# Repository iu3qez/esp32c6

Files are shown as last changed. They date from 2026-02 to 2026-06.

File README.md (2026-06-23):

# C6MacroSwitch

Interruttore/scene-controller Zigbee a batteria basato su ESP32-C6-WROOM-1-N8:
6 tasti meccanici Kailh Choc, LED di stato, alimentazione Li-ion 1S con LDO
very-low-dropout (XC6220B331), USB-C per programmazione via USB nativo,
charger MCP73831 predisposto ma non montato (DNP).

Progetto [Zener](https://github.com/diodeinc/pcb) (`pcb` CLI, richiede KiCad 10.x).

- Spec: `../docs/superpowers/specs/2026-06-11-c6-zigbee-macro-switch-design.md`
- Sourcing LCSC: `SOURCING.md`

## Comandi

```bash
pcb build C6MacroSwitch.zen    # valida il design
pcb layout C6MacroSwitch.zen   # sincronizza layout/C6MacroSwitch/layout.kicad_pcb
pcb open C6MacroSwitch.zen     # apre il layout in KiCad
pcb bom C6MacroSwitch.zen      # BOM con sourcing
```

Il round-trip KiCad 10 (salvataggio nativo → `pcb build`/`pcb layout`) è
verificato e funziona.

## Mappa GPIO

| GPIO | Funzione |
|---|---|
| IO0–IO5 | Tasti macro KEY1–KEY6 (LP-GPIO: wake da deep sleep, pull-up interni) |
| IO6 | ADC partitore batteria (1M/1M + 100nF) |
| IO8 | strapping, pullup 10k (download mode) |
| IO9 | Boot (pull-up 10k + tasto) |
| IO10 | LED di stato (verde, attivo alto) |
| IO12/IO13 | USB D−/D+ (USB nativo) |
| EN | Reset (pull-up 10k + 1µF + tasto) |

## Alimentazione

```
J_BAT (JST-PH) → Q_RVP/D_RVP (protezione inversione) → J_IMEAS (jumper misura corrente) → XC6220 → 3V3
USB VBUS → MCP73831 (DNP) → BAT+   |   USB VBUS → 1N5817W (DNP) → ingresso LDO
```

- Rimuovendo lo shunt da J_IMEAS si misura l'assorbimento totale a batteria.
- Protezione inversione batteria: montare ESATTAMENTE UNO tra Q_RVP
  (AO3401A, basse perdite) e D_RVP (1N5817W, semplice, ~300 mV di caduta);
  mai entrambi.
- D_USB_PWR (DNP) permette flash/test da USB senza batteria.
  **Attenzione:** mai montarlo con batteria collegata e jumper J_IMEAS
  inserito (bypassa il charger).
- Charger e relativi R/LED tutti DNP sulle prime board.
- Cutoff batteria firmware consigliato ~3,4 V (sotto, il rail esce di
  regolazione durante i burst TX).

## Note di popolamento

- SW1–SW6 (Kailh Choc CPG135001D01): esauriti su LCSC, montaggio in proprio.
- Tutti i passivi 0603

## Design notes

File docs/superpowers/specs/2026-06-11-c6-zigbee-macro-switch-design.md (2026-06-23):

# Design: C6 Zigbee Macro Switch (variante Zener)

Data: 2026-06-11
Branch: `dev-zener`
Stato: in attesa di approvazione spec

## Contesto e motivazione

Il progetto atopile originale (dev board ESP32-C6 con CH340G, doppio USB-C,
header verso keypad esterno) è bloccato: atopile ≤0.15.7 non rilegge i
`.kicad_pcb` salvati da KiCad 10 (issue atopile#1822). Si riparte prendendo
solo l'idea di fondo e si migra a `pcb` di Diode Inc. (linguaggio Zener,
file `.zen`), che richiede nativamente KiCad 10.x.

Il vecchio progetto ato resta nel repo come riferimento, intatto.

## Cosa si costruisce

Un interruttore/scene-controller **Zigbee a batteria** basato su ESP32-C6:
6 tasti macro, 1 LED di stato, alimentazione Li-ion 1S con LDO
very-low-dropout / low-IQ, USB-C per programmazione, charger predisposto ma
non montato (DNP) sulle prime board.

## Vincoli vincolanti (richieste esplicite)

1. **Modulo**: ESP32-C6-WROOM-1-N8, identico al progetto precedente
   (LCSC **C5366877**) — già disponibile in casa.
2. **Connettore USB-C**: identico al progetto precedente, Korean Hroparts
   TYPE-C-31-M-12 (LCSC **C165948**).
3. **Tasti macro**: switch meccanici Kailh Choc CPG135001D01
   (LCSC **C400229**), identici al keypad del progetto precedente.
4. **Tutti gli altri componenti**: disponibili su **LCSC con stock > 0** al
   momento del part picking.
5. **Resistenze e condensatori: package 0603**.
6. Toolchain: `diodeinc/pcb` (Zener), nuovo branch `dev-zener`.

## Architettura

```
USB-C (C165948) ──VBUS──> [Charger MCP73831/TP4054, DNP] ──> BAT+
   │ D+/D-                                                    │
   │                                              JST-PH 2p ──┤
   └──> ESP32-C6 USB nativo (GPIO12/13)                       │
                                                              ▼
                                            J_IMEAS (jumper misura corrente)
                                                              │
                                                              ▼
                                       LDO 3.3V VLDO/low-IQ (XC6220B331*)
                                                              │
                                                              ▼
ESP32-C6-WROOM-1-N8 (C5366877) <── 3V3 ── partitore ADC batteria (≥1 MΩ)
   ├── GPIO0..GPIO5: 6 tasti macro (2×3), LP-GPIO, wake da deep sleep,
   │                 pull-up interni → nessuna resistenza esterna
   ├── GPIO8 (o libero): LED di stato (normalmente spento)
   ├── EN: pull-up 10k + C 1uF + tasto reset
   └── GPIO9: tasto boot (pull-up interno/10k)
```

\* Candidato primario LDO: Torex XC6220B331 (1 A, dropout ~100 mV @ 300 mA,
IQ ~8 µA). Fallback se non a stock su LCSC: TLV755P-33, ME6217C33.
La scelta finale si fa in fase di picking col vincolo stock > 0.

## Componenti

| Blocco | Parte | Note |
|---|---|---|
| MCU/radio | ESP32-C6-WROOM-1-N8 | LCSC C5366877, fissato |
| USB-C | TYPE-C-31-M-12 | LCSC C165948, fissato; CC1/CC2 pulldown 5.1k 0603 |
| LDO | XC6220B331 (candidato) | SOT-25; cap in/out ceramici 0603 (valori da datasheet, tipicamente 1–10 µF) |
| Charger (DNP) | MCP73831 o TP4054, SOT-23-5 | + R prog 0603 + LED charge; footprint montati, BOM vuota |
| Batteria | JST-PH 2 pin SMT | Li-ion/LiPo 1S |
| Misura corrente | header 2 pin 2.54 mm + shunt | in serie al positivo batteria (a monte dell'LDO): shunt rimosso → amperometro in serie; misura il consumo totale incluso IQ dell'LDO |
| Alimentazione da USB senza batteria | Schottky SOD-123 (DNP) | da VBUS all'ingresso LDO (a valle del jumper): permette flash/test senza batteria; DNP se non serve. L'LDO regge Vin 5 V |
| Monitor batteria | 2× R ≥1 MΩ 0603 + C filtro | su ADC del C6 |
| Tasti macro | 6× Kailh Choc CPG135001D01 | LCSC **C400229**, switch meccanico low-profile come nel keypad precedente (footprint/symbol già in `parts/Kailh_CPG135001D01/`) |
| Tasti servizio | 2× tattile SMD (reset + boot) | LCSC stock >0 |
| LED stato | LED 0603 + R 1k 0603 | su GPIO libero |
| EN | R 10k + C 1 µF 0603 | reset RC classico |

Decoupling: 100 nF 0603 vicino al modulo + bulk 10 µF 0603 sul rail 3V3
(il WROOM ha già i regolatori interni di decoupling principali on-module;
si segue la app note Espressif).

## Connessioni GPIO

| GPIO | Funzione | Perché |
|---|---|---|
| GPIO0–GPIO5 | 6 tasti macro verso GND | LP-GPIO: deep-sleep wake, pull-up interni |
| GPIO9 | Boot + tasto | strapping pin standard |
| GPIO12/13 | USB D-/D+ | USB nativo (flash + console) |
| EN | Reset + RC | |
| GPIO8 | LED stato | strapping ma utilizzabile come output LED |
| GPIO6 | ADC partitore batteria | ADC1_CH6, ultimo canale ADC libero (canali ADC del C6: GPIO0–6) |

Nota: se in fase di implementazione emerge un conflitto su GPIO6, si sposta
un tasto su un GPIO non-LP accettando il wake solo dagli altri 5 tasti.

## Struttura progetto Zener

```
zener/                      # nuovo workspace pcb, non tocca il progetto ato
  pcb.toml                  # manifest board + dipendenze registry
  C6MacroSwitch.zen         # board top-level
  components/               # parti locali (WROOM-1-N8, TYPE-C-31-M-12, ...)
    ...                     # .zen + .kicad_sym + .kicad_mod riusati dal vecchio repo dove possibile
  layout/                   # output pcb layout (.kicad_pcb)
```

- Generici (R, C, LED, JST, tactile) da `@stdlib` o dal registry diodeinc
  (`pcb search`), con vincolo LCSC stock > 0.
- Per WROOM-1-N8 e TYPE-C-31-M-12 si riusano simbolo/footprint KiCad già
  presenti in `parts/` del progetto ato (sono già verificati su board
  precedente), incapsulati in componenti Zener locali.
- Skill di lavoro installate in `.claude/skills/` (zener-language,
  registry-search, librarian, datasheet-reader, spice-sim): da usare in
  implementazione.

## Verifica / criteri di successo

1. `pcb build` senza errori sul board top-level.
2. `pcb layout` genera un `.kicad_pcb` che KiCad 10.0.3 apre senza warning
   di formato; round-trip salvataggio KiCad 10 → `pcb build` OK.
3. BOM: ogni parte (tranne modulo già in casa) con codice LCSC e stock > 0
   alla data del picking; R/C tutti 0603.
4. Netlist coerente con la tabella GPIO sopra (review manuale).

## Fuori scope

- Layout/sbroglio finale e forma della scheda (fase successiva).
- Firmware Zigbee.
- Ricarica montata (prime board: charger DNP).

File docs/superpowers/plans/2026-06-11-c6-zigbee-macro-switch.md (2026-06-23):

# C6 Zigbee Macro Switch — Implementation Plan (Zener/pcb)

> **For agentic workers:** REQUIRED SUB-SKILL: Use superpowers:subagent-driven-development (recommended) or superpowers:executing-plans to implement this plan task-by-task. Steps use checkbox (`- [ ]`) syntax for tracking.

**Goal:** Board Zener completa e validata (`pcb build` pulito, layout generato apribile in KiCad 10) per l'interruttore Zigbee a batteria con ESP32-C6, secondo la spec `docs/superpowers/specs/2026-06-11-c6-zigbee-macro-switch-design.md`.

**Architecture:** Workspace `pcb` (board repository) in `zener/` sul branch `dev-zener`. Componenti specifici come moduli Zener locali in `zener/components/`, riusando i `.kicad_sym`/`.kicad_mod` già verificati in `parts/` del progetto ato. Generici (R, C, LED, header) da `@stdlib`. Top-level `C6MacroSwitch.zen` con catena di potenza batteria→jumper→LDO→3V3, 6 tasti Choc su GPIO0–5, LED su GPIO8, USB nativo su IO12/13.

**Tech Stack:** `pcb` CLI (diodeinc), linguaggio Zener (Starlark), KiCad 10.0.3, stdlib `@stdlib`.

**Regole trasversali (valgono per OGNI task):**
- Prima di scrivere/modificare `.zen`: skill `zener-language` già caricata in `.claude/skills/`.
- Dopo ogni modifica agli import: `pcb sync` dentro `zener/`, poi `pcb build`.
- R/C sempre `package="0603"`.
- Ogni parte nuova: verificare LCSC stock > 0 (vedi Task 8) prima di fissarla.
- Preservare eventuali commenti `# pcb:sch`.
- Commit frequenti, messaggi conventional-commits, MAI Co-Authored-By.

---

### Task 1: Installare il tool `pcb`

**Files:** nessuno (toolchain).

- [ ] **Step 1: Installa**

```bash
curl -fsSL https://raw.githubusercontent.com/diodeinc/pcb/main/install.sh | bash
```

Installa in `$HOME/.local/bin` (già nel PATH: `ato` sta lì).

- [ ] **Step 2: Verifica**

```bash
pcb --version
```

Atteso: versione ≥ 0.3.92. Se il comando non esiste, `export PATH="$HOME/.local/bin:$PATH"`.

- [ ] **Step 3: Verifica che trovi KiCad**

```bash
kicad-cli version   # atteso: 10.0.3
```

Nessun commit (nessun file di repo toccato).

---

### Task 2: Scaffold del workspace `zener/`

**Files:**
- Create: `zener/pcb.toml`
- Create: `zener/C6MacroSwitch.zen`

- [ ] **Step 1: Genera lo scaffold con il tool** (così la struttura è quella canonica della versione installata)

```bash
cd /home/sf/src/esp32c6/esp32c6
pcb new board C6MacroSwitch https://github.com/iu3qez/esp32c6
```

Se `pcb new board` crea una directory `C6MacroSwitch/`, rinominarla in `zener/`:

```bash
mv C6MacroSwitch zener
```

Ispeziona cosa ha generato (`ls -R zener/`) e adatta i passi seguenti alla struttura reale; i contenuti sotto sono il riferimento atteso.

- [ ] **Step 2: `zener/pcb.toml`** (verifica/adatta quello generato)

```toml
[workspace]
name = "esp32c6-zener"

[board]
name = "C6MacroSwitch"
path = "C6MacroSwitch.zen"
description = "ESP32-C6 Zigbee battery-powered macro switch"
```

- [ ] **Step 3: Board minimale `zener/C6MacroSwitch.zen`**

```zen
Board(name="C6MacroSwitch", layout_path="layout/C6MacroSwitch", layers=2)

VBAT = Power("VBAT")
VDD_3V3 = Power("3V3")
GND = Ground("GND")
```

- [ ] **Step 4: Valida**

```bash
cd zener && pcb build
```

Atteso: build OK, zero errori (board vuota è legale; se `Board()` richiede argomenti diversi nella versione installata, vedere `pcb doc --package @stdlib` per `board_config`).

- [ ] **Step 5: Commit**

```bash
git add zener && git commit -m "feat(zener): scaffold pcb workspace for C6MacroSwitch"
```

---

### Task 3: Componente ESP32-C6-WROOM-1-N8 (riuso footprint/symbol)

**Files:**
- Create: `zener/components/ESP32C6WROOM1N8/ESP32C6WROOM1N8.zen`
- Copy: `parts/Espressif_Systems_ESP32_C6_WROOM_1_N8/ESP32-C6-WROOM-1-N8.kicad_sym` → `zener/components/ESP32C6WROOM1N8/`
- Copy: `parts/Espressif_Systems_ESP32_C6_WROOM_1_N8/WIRELM-SMD_ESP32-C6-WROOM-1.kicad_mod` → `zener/components/ESP32C6WROOM1N8/`

- [ ] **Step 1: Copia symbol e footprint**

```bash
mkdir -p zener/components/ESP32C6WROOM1N8
cp parts/Espressif_Systems_ESP32_C6_WROOM_1_N8/ESP32-C6-WROOM-1-N8.kicad_sym zener/components/ESP32C6WROOM1N8/
cp parts/Espressif_Systems_ESP32_C6_WROOM_1_N8/WIRELM-SMD_ESP32-C6-WROOM-1.kicad_mod zener/components/ESP32C6WROOM1N8/
```

- [ ] **Step 2: Ispeziona i nomi pin del symbol** (servono per la mappa `pins`)

```bash
grep -oE '\(name "[^"]+"' zener/components/ESP32C6WROOM1N8/ESP32-C6-WROOM-1-N8.kicad_sym | sort -u
grep -oE '\(number "[^"]+"' zener/components/ESP32C6WROOM1N8/ESP32-C6-WROOM-1-N8.kicad_sym | sort -u
```

Pinout di riferimento (dal part ato, verificato su board precedente): EN=3, GND=1,28–37, IO0=8, IO1=9, IO2=27, IO3=26, IO4=4, IO5=5, IO6=6, IO7=7, IO8=10, IO9=15, IO10=11, IO11=12, IO12=13, IO13=14, IO15=23, IO18=16, IO19=17, IO20=18, IO21=19, IO22=20, IO23=21, P3V3=2, RXD0=24, TXD0=25.

- [ ] **Step 3: Scrivi `ESP32C6WROOM1N8.zen`**

```zen
EN = io(Net)
P3V3 = io(Power)
GND = io(Ground)
IO0 = io(Net); IO1 = io(Net); IO2 = io(Net); IO3 = io(Net)
IO4 = io(Net); IO5 = io(Net); IO6 = io(Net); IO7 = io(Net, optional=True)
IO8 = io(Net); IO9 = io(Net)
IO10 = io(Net, optional=True); IO11 = io(Net, optional=True)
IO12 = io(Net); IO13 = io(Net)
IO15 = io(Net, optional=True); IO18 = io(Net, optional=True)
IO19 = io(Net, optional=True); IO20 = io(Net, optional=True)
IO21 = io(Net, optional=True); IO22 = io(Net, optional=True)
IO23 = io(Net, optional=True)
RXD0 = io(Net, optional=True); TXD0 = io(Net, optional=True)

Component(
    name = "ESP32C6WROOM1N8",
    symbol = Symbol(library = "./ESP32-C6-WROOM-1-N8.kicad_sym"),
    footprint = "./WIRELM-SMD_ESP32-C6-WROOM-1.kicad_mod",
    part = Part(mpn = "ESP32-C6-WROOM-1-N8", manufacturer = "Espressif Systems"),
    pins = {
        "EN": EN, "P3V3": P3V3, "GND": GND,
        "IO0": IO0, "IO1": IO1, "IO2": IO2, "IO3": IO3,
        "IO4": IO4, "IO5": IO5, "IO6": IO6, "IO7": IO7,
        "IO8": IO8, "IO9": IO9, "IO10": IO10, "IO11": IO11,
        "IO12": IO12, "IO13": IO13, "IO15": IO15, "IO18": IO18,
        "IO19": IO19, "IO20": IO20, "IO21": IO21, "IO22": IO22,
        "IO23": IO23, "RXD0": RXD0, "TXD0": TXD0,
    },
)
```

Note d'adattamento (decidere in base all'output di Step 2 e di `pcb build`):
- Se il symbol espone i pin per NUMERO e non per nome, le chiavi di `pins` diventano i numeri (`"3": EN, "2": P3V3, ...` secondo il pinout di riferimento sopra).
- Se il symbol contiene già la property footprint corretta, rimuovere `footprint=` dal `Component()` (il symbol è source of truth).
- Aggiungere la property LCSC: se `pcb build`/BOM non la riporta, aggiungere `properties = {"LCSC": "C5366877"}` al `Component()`.

- [ ] **Step 4: Valida il componente**

```bash
cd zener && pcb build components/ESP32C6WROOM1N8/ESP32C6WROOM1N8.zen
```

Atteso: build OK. Errori tipici: pin del symbol non mappato (aggiungerlo a `pins` con `io(Net, optional=True)`), nome pin sbagliato (correggere chiave).

- [ ] **Step 5: Commit**

```bash
git add zener/components/ESP32C6WROOM1N8
git commit -m "feat(zener): ESP32-C6-WROOM-1-N8 component (reused verified sym/fp)"
```

---

### Task 4: Componente USB-C TYPE-C-31-M-12

**Files:**
- Create: `zener/components/TYPEC31M12/TYPEC31M12.zen`
- Copy: `parts/Korean_Hroparts_Elec_TYPE_C_31_M_12/TYPE-C-31-M-12.kicad_sym` e `USB-C_SMD-TYPE-C-31-M-12_1.kicad_mod` → `zener/components/TYPEC31M12/`

- [ ] **Step 1: Copia file**

```bash
mkdir -p zener/components/TYPEC31M12
cp parts/Korean_Hroparts_Elec_TYPE_C_31_M_12/TYPE-C-31-M-12.kicad_sym zener/components/TYPEC31M12/
cp parts/Korean_Hroparts_Elec_TYPE_C_31_M_12/USB-C_SMD-TYPE-C-31-M-12_1.kicad_mod zener/components/TYPEC31M12/
```

- [ ] **Step 2: Ispeziona pin del symbol** (stesso metodo grep del Task 3, Step 2).

Pinout di riferimento ato: CC1=A5, CC2=B5, D_N=A7+B7, D_P=A6+B6, EH=1..4, GND=A1B12+B1A12, SBU1=A8, SBU2=B8, VBUS=A4B9+B4A9.

- [ ] **Step 3: Scrivi `TYPEC31M12.zen`**

```zen
load("@stdlib/interfaces.zen", "Usb2")

VBUS = io(Power)
GND = io(Ground)
USB = io(Usb2)
CC1 = io(Net)
CC2 = io(Net)
SBU1 = io(Net, optional=True)
SBU2 = io(Net, optional=True)
SHIELD = io(Net)

Component(
    name = "TYPEC31M12",
    symbol = Symbol(library = "./TYPE-C-31-M-12.kicad_sym"),
    footprint = "./USB-C_SMD-TYPE-C-31-M-12_1.kicad_mod",
    part = Part(mpn = "TYPE-C-31-M-12", manufacturer = "Korean Hroparts Elec"),
    pins = {
        "VBUS": VBUS, "GND": GND,
        "D_P": USB.DP, "D_N": USB.DM,
        "CC1": CC1, "CC2": CC2,
        "SBU1": SBU1, "SBU2": SBU2,
        "EH": SHIELD,
    },
)
```

Note d'adattamento: come Task 3 (chiavi `pins` = nomi reali del symbol; se i pad multipli A4B9/B4A9 sono pin distinti nel symbol, mappare entrambi sulla stessa net: `"A4B9": VBUS, "B4A9": VBUS`). Verificare i nomi dei campi di `Usb2` con `pcb doc --package @stdlib` (`DP`/`DM` vs `D_P`/`D_N`) e usare quelli reali.

- [ ] **Step 4: Valida**

```bash
cd zener && pcb build components/TYPEC31M12/TYPEC31M12.zen
```

- [ ] **Step 5: Commit**

```bash
git add zener/components/TYPEC31M12
git commit -m "feat(zener): TYPE-C-31-M-12 USB-C connector component"
```

---

### Task 5: Componente Kailh Choc CPG135001D01

**Files:**
- Create: `zener/components/KailhChoc/KailhChoc.zen`
- Copy: `parts/Kailh_CPG135001D01/CPG135001D01.kicad_sym` e `KEY-TH_CPG135001D0X.kicad_mod` → `zener/components/KailhChoc/`

- [ ] **Step 1: Copia file**

```bash
mkdir -p zener/components/KailhChoc
cp parts/Kailh_CPG135001D01/CPG135001D01.kicad_sym zener/components/KailhChoc/
cp parts/Kailh_CPG135001D01/KEY-TH_CPG135001D0X.kicad_mod zener/components/KailhChoc/
```

- [ ] **Step 2: Scrivi `KailhChoc.zen`** (2 pin: 1 e 2)

```zen
P1 = io(Net)
P2 = io(Net)

Component(
    name = "KailhChoc",
    symbol = Symbol(library = "./CPG135001D01.kicad_sym"),
    footprint = "./KEY-TH_CPG135001D0X.kicad_mod",
    part = Part(mpn = "CPG135001D01", manufacturer = "Kailh"),
    pins = {"1": P1, "2": P2},
)
```

(Adattare chiavi `pins` ai nomi reali del symbol come nei task precedenti.)

- [ ] **Step 3: Valida e committa**

```bash
cd zener && pcb build components/KailhChoc/KailhChoc.zen
git add zener/components/KailhChoc
git commit -m "feat(zener): Kailh Choc CPG135001D01 switch component"
```

---

### Task 6: Componenti riusati minori — tactile button e Schottky

**Files:**
- Create: `zener/components/TactileTSA061B/TactileTSA061B.zen` (+ sym/fp copiati da `parts/BZCN_TSA061B2808B/`)
- Create: `zener/components/SS1N5817W/SS1N5817W.zen` (+ sym/fp copiati da `parts/Slkor_1N5817W/`)

- [ ] **Step 1: Tactile (reset/boot), pinout ato: 1,2 = lato A; 3,4 = lato B; 5 = ground/frame**

```bash
mkdir -p zener/components/TactileTSA061B
cp parts/BZCN_TSA061B2808B/*.kicad_sym parts/BZCN_TSA061B2808B/*.kicad_mod zener/components/TactileTSA061B/
```

`TactileTSA061B.zen` (verificare i nomi file copiati e i pin reali col grep):

```zen
A = io(Net)
B = io(Net)

Component(
    name = "TactileTSA061B",
    symbol = Symbol(library = "./TSA061B2808B.kicad_sym"),
    footprint = "./KEY-SMD_4P-L6.0-W6.0-LS8.0.kicad_mod",
    part = Part(mpn = "TSA061B2808B", manufacturer = "BZCN"),
    pins = {"1": A, "2": A, "3": B, "4": B, "5": B},
)
```

- [ ] **Step 2: Schottky 1N5817W (per VBUS→LDO, DNP), pinout ato: 2=anodo, 1=catodo**

```bash
mkdir -p zener/components/SS1N5817W
cp parts/Slkor_1N5817W/*.kicad_sym parts/Slkor_1N5817W/*.kicad_mod zener/components/SS1N5817W/
```

```zen
A = io(Net)
K = io(Net)

Component(
    name = "SS1N5817W",
    symbol = Symbol(library = "./1N5817W.kicad_sym"),
    footprint = "./SOD-123_L2.8-W1.8-LS3.7-RD.kicad_mod",
    part = Part(mpn = "1N5817W", manufacturer = "Slkor"),
    pins = {"1": K, "2": A},
)
```

(I nomi esatti di sym/fp si leggono con `ls parts/BZCN_TSA061B2808B/ parts/Slkor_1N5817W/` e dai trait `is_atomic_part` nei rispettivi `.ato`; adattare.)

- [ ] **Step 3: Valida entrambi e committa**

```bash
cd zener && pcb build components/TactileTSA061B/TactileTSA061B.zen components/SS1N5817W/SS1N5817W.zen
git add zener/components/TactileTSA061B zener/components/SS1N5817W
git commit -m "feat(zener): tactile button and 1N5817W Schottky components"
```

---

### Task 7: Parti nuove — LDO, charger (DNP), JST-PH

Per ognuna: **prima** cercare nel registry (skill `registry-search`: `pcb search -m registry:components <query>`, poi `pcb search -m registry:modules <query>`); usare il package registry se esiste. Solo se assente, creare componente locale (skill `librarian` per il flusso symbol/footprint: scaricare da LCSC/EasyEDA con lo stesso metodo usato per le parti ato, o disegnare da datasheet con `datasheet-reader`).

- [ ] **Step 1: LDO XC6220B331MR-G**

```bash
cd zener && pcb search -m registry:components XC6220
pcb search XC6220B331MR-G
```

Verifica LCSC stock >0 per XC6220B331MR-G (pagina LCSC; vedi Task 8 Step 1 per il metodo). Se stock = 0, fallback nell'ordine: TLV755P-33 (`TLV75533PDBVR`), ME6217C33M5G — stesso giro di ricerca registry + stock. Il componente espone almeno: `VIN = io(Power)`, `VOUT = io(Power)`, `GND = io(Ground)` (+ `CE`/`EN` se presente nel package scelto: legarlo a VIN nel top-level).

- [ ] **Step 2: Charger MCP73831 (o TP4054)**

```bash
pcb search -m registry:components MCP73831
pcb search MCP73831
```

Stock check su `MCP73831T-2ACI/OT`; fallback `TP4054`. Servono: `VDD`, `VBAT`, `STAT`, `PROG`, `VSS`. La R di PROG (0603) fissa la corrente di carica: scegliere `2kohm` (≈500 mA) — verrà montata solo col charger, quindi `dnp=True` insieme a esso.

- [ ] **Step 3: Connettore batteria JST-PH 2 pin**

```bash
pcb search -m registry:components "JST PH"
pcb search S2B-PH-K-S
```

Candidato THT side-entry `S2B-PH-K-S` (JST) o equivalente SMT; vincolo: LCSC stock >0. Se assente nel registry, creare `zener/components/JstPh2/` col flusso librarian.

- [ ] **Step 4: Valida e committa** (file effettivi dipendono da registry vs locale)

```bash
cd zener && pcb sync && pcb build
git add zener && git commit -m "feat(zener): add LDO, charger (DNP) and battery connector parts"
```

---

### Task 8: Verifica sourcing LCSC (stock > 0)

**Files:**
- Create: `zener/SOURCING.md`

- [ ] **Step 1: Per OGNI MPN scelto nei Task 3–7, verifica stock su LCSC**

Metodo: `WebFetch` su `https://www.lcsc.com/search?q=<MPN>` oppure API pubblica `https://wmsc.lcsc.com/ftps/wm/search/global-search?keyword=<MPN>` e leggere il campo stock. In alternativa la pagina prodotto diretta se il codice C è noto (es. `https://www.lcsc.com/product-detail/C400229.html`).

- [ ] **Step 2: Compila `zener/SOURCING.md`**

```markdown
# Sourcing (LCSC) — verificato YYYY-MM-DD

| Ref | Parte | LCSC | Stock | Note |
|---|---|---|---|---|
| U1 | ESP32-C6-WROOM-1-N8 | C5366877 | n/a | già in casa |
| J1 | TYPE-C-31-M-12 | C165948 | <stock> | |
| SW1–6 | CPG135001D01 | C400229 | <stock> | |
| U2 | <LDO scelto> | <C...> | <stock> | |
| U3 | <charger> | <C...> | <stock> | DNP |
| ... | | | | |
```

Regola: se una parte ha stock 0, tornare al task corrispondente e usare il fallback. R/C 0603 generici: verificare che il valore esista su LCSC in 0603 (sono basic part, di norma sì) e annotare un codice C di riferimento.

- [ ] **Step 3: Commit**

```bash
git add zener/SOURCING.md && git commit -m "docs(zener): LCSC sourcing table with stock verification"
```

---

### Task 9: Top-level `C6MacroSwitch.zen` — wiring completo

**Files:**
- Modify: `zener/C6MacroSwitch.zen`

- [ ] **Step 1: Scrivi il top-level completo**

```zen
load("@stdlib/interfaces.zen", "Usb2")

Resistor  = Module("@stdlib/generics/Resistor.zen")
Capacitor = Module("@stdlib/generics/Capacitor.zen")
Led       = Module("@stdlib/generics/Led.zen")
PinHeader = Module("@stdlib/generics/PinHeader.zen")

Esp32   = Module("./components/ESP32C6WROOM1N8/ESP32C6WROOM1N8.zen")
UsbC    = Module("./components/TYPEC31M12/TYPEC31M12.zen")
Choc    = Module("./components/KailhChoc/KailhChoc.zen")
Tactile = Module("./components/TactileTSA061B/TactileTSA061B.zen")
Schottky = Module("./components/SS1N5817W/SS1N5817W.zen")
# + LDO / charger / JST dai package del Task 7 (registry URL o ./components/...)

Board(name="C6MacroSwitch", layout_path="layout/C6MacroSwitch", layers=2)

GND      = Ground("GND")
VBAT     = Power("VBAT")          # dal connettore batteria
VBAT_SW  = Power("VBAT_SW")       # a valle del jumper misura corrente
VDD_3V3  = Power(voltage="3.3V", name="3V3")
VBUS     = Power("VBUS")

# Batteria -> jumper misura corrente -> LDO
# J_BAT (JST-PH): pin 1 = VBAT, pin 2 = GND  (istanza dal package Task 7)
PinHeader(name="J_IMEAS", pins=2, pitch="2.54mm", P1=VBAT, P2=VBAT_SW)

# LDO (XC6220B331): VIN=VBAT_SW, VOUT=VDD_3V3, GND=GND (+ CE a VBAT_SW se presente)
Capacitor(name="C_LDO_IN",  value="1uF",  package="0603", P1=VBAT_SW, P2=GND)
Capacitor(name="C_LDO_OUT", value="1uF",  package="0603", P1=VDD_3V3, P2=GND)
# (valori da datasheet del LDO scelto; XC6220: 1uF in/out ceramici minimi)

# USB-C: dati al C6, VBUS al charger (DNP) e alla Schottky (DNP)
usb_bus = Usb2("USB")
UsbC(name="J_USB", VBUS=VBUS, GND=GND, USB=usb_bus, CC1=Net("CC1"), CC2=Net("CC2"), SHIELD=GND)
Resistor(name="R_CC1", value="5.1kohm", package="0603", P1=Net("CC1"), P2=GND)
Resistor(name="R_CC2", value="5.1kohm", package="0603", P1=Net("CC2"), P2=GND)

# Alimentazione da USB senza batteria (DNP): VBUS -> Schottky -> VBAT_SW
Schottky(name="D_USB_PWR", A=VBUS, K=VBAT_SW, dnp=True)

# Charger (DNP): VDD=VBUS, VBAT=VBAT (a monte del jumper), VSS=GND
# R_PROG 2k (DNP), LED_CHG + R 1k (DNP) su STAT
# (istanze dal package Task 7, tutte con dnp=True)

# ESP32-C6
esp = Esp32(
    name="U1",
    P3V3=VDD_3V3, GND=GND,
    EN=Net("EN"),
    IO0=Net("KEY1"), IO1=Net("KEY2"), IO2=Net("KEY3"),
    IO3=Net("KEY4"), IO4=Net("KEY5"), IO5=Net("KEY6"),
    IO6=Net("VBAT_SENSE"),
    IO8=Net("LED"),
    IO9=Net("BOOT"),
    IO12=usb_bus.DM, IO13=usb_bus.DP,
)
Capacitor(name="C_ESP_BULK", value="10uF",  package="0603", P1=VDD_3V3, P2=GND)
Capacitor(name="C_ESP_DEC",  value="100nF", package="0603", P1=VDD_3V3, P2=GND)

# EN: pull-up + RC + tasto reset
Resistor(name="R_EN", value="10kohm", package="0603", P1=VDD_3V3, P2=Net("EN"))
Capacitor(name="C_EN", value="1uF", package="0603", P1=Net("EN"), P2=GND)
Tactile(name="SW_RST", A=Net("EN"), B=GND)

# Boot: tasto su GPIO9 + pull-up
Resistor(name="R_BOOT", value="10kohm", package="0603", P1=VDD_3V3, P2=Net("BOOT"))
Tactile(name="SW_BOOT", A=Net("BOOT"), B=GND)

# 6 tasti macro Choc: GPIO -> switch -> GND (pull-up interni, LP-GPIO wake)
for i in range(6):
    Choc(name="SW%d" % (i + 1), P1=Net("KEY%d" % (i + 1)), P2=GND)

# LED di stato
Resistor(name="R_LED", value="1kohm", package="0603", P1=Net("LED"), P2=Net("LED_A"))
Led(name="D_LED", color="green", package="0603", A=Net("LED_A"), K=GND)

# Partitore batteria su ADC (GPIO6) — alta impedenza + filtro
Resistor(name="R_VBAT_TOP", value="1Mohm", package="0603", P1=VBAT_SW, P2=Net("VBAT_SENSE"))
Resistor(name="R_VBAT_BOT", value="1Mohm", package="0603", P1=Net("VBAT_SENSE"), P2=GND)
Capacitor(name="C_VBAT_SENSE", value="100nF", package="0603", P1=Net("VBAT_SENSE"), P2=GND)
```

Adattamenti previsti: nomi dei campi `Usb2` (`DP`/`DM`) e firma esatta di `PinHeader`/`Led` da verificare con `pcb doc --package @stdlib`; istanze LDO/charger/JST secondo l'API reale dei package scelti nel Task 7. Il loop `for` Starlark è legale a top-level di modulo; se la versione installata richiede istanze esplicite, srotolare in 6 righe.

- [ ] **Step 2: Sync e build**

```bash
cd zener && pcb sync && pcb build
```

Atteso: zero errori. Iterare sugli errori (pin mismatch, firme generics) finché pulito.

- [ ] **Step 3: Review netlist contro la tabella GPIO della spec**

```bash
pcb build 2>&1 | tail -5   # conferma OK
```

Confronto manuale: KEY1–6→IO0–5, VBAT_SENSE→IO6, LED→IO8, BOOT→IO9, USB DM/DP→IO12/IO13, EN con RC.

- [ ] **Step 4: Commit**

```bash
git add zener && git commit -m "feat(zener): complete C6MacroSwitch top-level wiring"
```

---

### Task 10: Layout e round-trip KiCad 10

- [ ] **Step 1: Genera il layout**

```bash
cd zener && pcb layout
```

Atteso: crea `zener/layout/C6MacroSwitch/*.kicad_pcb` senza errori.

- [ ] **Step 2: Verifica apertura KiCad 10 (headless)**

```bash
kicad-cli pcb export svg zener/layout/C6MacroSwitch/*.kicad_pcb -o /tmp/c6ms_check.svg --layers F.Cu 2>&1 | tail -3
```

Atteso: export senza errori = KiCad 10 legge il file.

- [ ] **Step 3: Round-trip: tocca e risalva con KiCad 10, poi ricompila**

Aprire con `pcb open` (o KiCad GUI), salvare (Ctrl+S, il file viene riscritto in formato KiCad 10), poi:

```bash
cd zener && pcb build && pcb layout
```

Atteso: nessun errore — è il test che con atopile falliva (motivo della migrazione).

- [ ] **Step 4: Commit**

```bash
git add zener/layout && git commit -m "feat(zener): initial generated layout, KiCad 10 round-trip verified"
```

---

### Task 11: Chiusura — README, push, memoria

- [ ] **Step 1: `zener/README.md`** breve: cosa è la board, comandi (`pcb build` / `pcb layout` / `pcb open`), link alla spec, tabella GPIO.

- [ ] **Step 2: Push**

```bash
git push
```

- [ ] **Step 3: Aggiorna la memoria di progetto** (`/home/sf/.claude/projects/-home-sf-src-esp32c6-esp32c6/memory/`): nuova nota `zener-migration` con stato raggiunto e prossimi passi (placement, sbroglio), e link `[[atopile-kicad10-incompatibility]]`.

---

## Fuori piano (fasi successive, non in questo piano)

- Placement e sbroglio finale in KiCad (interattivo con l'utente).
- Forma scheda / meccanica / keycap.
- Ordine JLCPCB/LCSC e firmware Zigbee.

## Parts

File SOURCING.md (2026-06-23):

# Sourcing (LCSC) — verificato 2026-06-11

Stock letti dal campo `stockNumber` delle pagine prodotto lcsc.com.

## Parti principali

| Ref | Parte | LCSC | Stock | Note |
|---|---|---|---|---|
| U1 | ESP32-C6-WROOM-1-N8 (Espressif) | C5366877 | 5.396 | già in casa |
| J_USB | TYPE-C-31-M-12 (Korean Hroparts) | C165948 | 175.320 | |
| SW1–SW6 | CPG135001D01 (Kailh Choc) | C400229 | **0 — esaurito** | già in casa (customer-supplied); MOQ 1000 al restock |
| SW_RST, SW_BOOT | TSA061B2808B (BZCN) | C20624994 | 335 | stock basso, ok per prototipi |
| D_USB_PWR, D_RVP | 1N5817W (Slkor) | C5185908 | 12.100 | usato 2×, entrambi DNP |
| Q_RVP | AO3401A (Alpha & Omega, P-MOSFET SOT-23) | C15127 | 354.200 (verificato 2026-06-12) | protezione inversione batteria |
| U2 | XC6220B331MR-G (Torex, LDO 3.3V 1A) | C86534 | 9.867 | C_LDO_IN/OUT 10 µF **0805** (vedi tabella passivi) |
| U3 | MCP73831T-2ACI/OT (Microchip, charger) | C424093 | 12.519 | DNP |
| J_BAT | S2B-PH-K-S(LF)(SN) (JST PH 2p) | C173752 | 87.260 | |

## Passivi 0603 (codici rappresentativi a stock)

| Valore | LCSC | Parte | Stock |
|---|---|---|---|
| 5,1 kΩ 1% | C23186 | UNI-ROYAL 0603WAF5101T5E | 233.800 |
| 10 kΩ 5% | C5362358 | TyoHM RMC 0603 10K | 1.700 |
| 1 kΩ 1% | C116692 | YAGEO AC0603FR-071KL | 5.000 |
| 1 MΩ 1% | C22935 | UNI-ROYAL 0603WAF1004T5E | 636.800 |
| 100 nF 50V X7R | C77055 | Murata GRM188R71H104KA93D | 1.199.900 |
| 1 µF 10V X7R | C95843 | Samsung CL10B105KP8NNNC | 50.000 |
| 10 µF 10V X5R | C19702 | Samsung CL10A106KP8NNNC | 1.307.180 |
| 10 µF 25V X7R 0805 (cap LDO) | C237493 | Murata GRM21BZ71E106KE15L | 45.475 (2026-06-13) |
| LED verde | C125101 | Lite-On LTST-C191TGKT | 42.000 |

## Avvertenze

- Molti codici "basic" storici risultavano a stock zero alla data di verifica
  (C25804, C21190, C14663, C15849, C72043…): i codici in tabella sono i
  sostituti verificati. Ricontrollare lo stock al momento dell'ordine.
- L'header J_IMEAS (2 pin 2,54 mm) e relativo shunt sono generici pin-header:
  qualunque codice a stock va bene (es. ricerca "pin header 2.54 1x2").
- D_USB_PWR: mai montato insieme a batteria collegata con jumper J_IMEAS
  inserito (bypassa il charger).

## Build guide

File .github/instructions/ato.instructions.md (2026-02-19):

---
description: ato is a declarative DSL to design electronics (PCBs) with.
applyTo: *.ato, ato.yaml
---

ato is a declarative DSL to design electronics (PCBs) with.
It is part of the atopile project.
Atopile is run by the vscode/cursor/windsurf extension.
The CLI (which is invoked by the extension) actually builds the project.

# Not available in ato

- if statements
- while loops
- functions (calls or definitions)
- classes
- objects
- exceptions
- generators

# Ato Syntax

ato sytax is heavily inspired by Python, but fully declarative.
ato thus has no procedural code, and no side effects.

## Examples of syntax

```ato
#pragma text
#pragma func("X")
# enable for loop syntax feature:
#pragma experiment("FOR_LOOP)

# --- Imports ---
# Standard import (newline terminated)
import ModuleName

# Import with multiple modules (newline terminated)
import Module1, Module2.Submodule

# Import from a specific file/source (newline terminated)
from "path/to/source.ato" import SpecificModule

# Multiple imports on one line (semicolon separated)
import AnotherModule; from "another/source.ato" import AnotherSpecific

# Deprecated import form (newline terminated)
# TODO: remove when unsupported
import DeprecatedModule from "other/source.ato"

# --- Top-level Definitions and Statements ---

pass
pass;

"docstring-like statement"
"docstring-like statement";

top_level_var = 123

# Compound statement
pass; another_var = 456; "another docstring"

# Block definitions
component MyComponent:
    # Simple statement inside block (newline terminated)
    pass

    # Multiple simple statements on one line (semicolon separated)
    pass; internal_flag = True

module AnotherBaseModule:
    pin base_pin
    base_param = 10

interface MyInterface:
    pin io

module DemoModule from AnotherBaseModule:
    # --- Declarations ---
    pin p1              # Pin declaration with name
    pin 1               # Pin declaration with number
    pin "GND"           # Pin declaration with string
    signal my_signal    # Signal definition
    a_field: AnotherBaseModule      # Field declaration with type hint

    # --- Assignments ---
    # Newline terminated:
    internal_variable = 123

    # Semicolon separated on one line:
    var_a = 1; var_b = "string"

    # Cumulative assignment (+=, -=) - Newline terminated
    value = 1
    value += 1; value -= 1

    # Set assignment (|=, &=) - Newline terminated
    flags |= 1; flags &= 2

    # --- Connections ---
    p1 ~ base_pin
    mif ~> bridge
    mif ~> bridge ~> bridge
    mif ~> bridge ~> bridge ~> mif
    bridge ~> mif
    mif <~ bridge
    mif <~ bridge <~ bridge
    mif <~ bridge <~ bridge <~ mif
    bridge <~ mif

    # Semicolon separated on one line:
    p_multi1 ~ my_signal; p_multi2 ~ sig_multi1

    # --- Retyping ---
    instance.x -> AnotherBaseModule

    # --- Instantiation ---
    instance = new MyComponent
    container = new MyComponent[10]
    templated_instance_a = new MyComponent
    templated_instance_b = new MyComponent<int_=1>
    templated_instance_c = new MyComponent<float_=2.5>
    templated_instance_d = new MyComponent<string_="hello">
    templated_instance_e = new MyComponent<int_=1, float_=2.5, string_="hello">
    templated_instance_f = new MyComponent<int_=1, float_=2.5, string_="hello", bool_=True>

    # Semicolon separated instantiations (via assignment):
    inst_a = new MyComponent; inst_b = new AnotherBaseModule

    # --- Traits ---
    trait trait_name
    trait trait_name<int_=1>
    trait trait_name<float_=2.5>
    trait trait_name<string_="hello">
    trait trait_name<bool_=True>
    trait trait_name::constructor
    trait trait_name::constructor<int_=1>

    # Semicolon separated on one line:
    trait TraitA; trait TraitB::constructor; trait TraitC<arg_=1>

    # --- Assertions ---
    assert x > 5V
    assert x < 10V
    assert 5V < x < 10V
    assert x >= 5V
    assert x <= 10V
    assert current within 1A +/- 10mA
    assert voltage within 1V +/- 10%
    assert resistance is 1kohm to 1.1kohm

    # Semicolon separated on one line:
    assert x is 1V; assert another_param is 2V

    # --- Loops ---
    for item in container:
        item ~ p1

    # For loop iterating over a slice
    for item in container[0:4]:
        pass
        item.value = 1; pass

    # For loop iterating over a list literal of field references
    for ref in [p1, x.1, x.GND]:
        pass

    # --- References and Indexing ---
    # Reference with array index assignment
    array_element = container[3]

    # --- Literals and Expressions ---
    # Integer
    int_val = 100
    neg_int_val = -50
    hex_val = 0xF1
    bin_val = 0b10
    oct_val = 0o10
    # Float
    float_val = 3.14
    # Physical quantities
    voltage: V = 5V
    resistance: ohm = 10kohm
    capacitance: F = 100nF
    # Bilateral tolerance
    tolerance_val = 1kohm +/- 10%
    tolerance_abs = 5V +/- 500mV
    tolerance_explicit_unit = 10A +/- 1A
    # Bounded quantity (range)
    voltage_range = 3V to 3.6V
    # Boolean
    is_enabled = True
    is_active = False
    # String
    message = "Hello inside module"

    # Arithmetic expressions
    sum_val = 1 + 2
    diff_val = 10 - 3ohm
    prod_val = 5 * 2mA
    div_val = 10V / 2kohm # Results in current
    power_val = 2**3
    complex_expr = (5 + 3) * 2 - 1
    flag_check = state | MASK_VALUE

    # Comparisons
    assert voltage within voltage_range
    assert length <= 5mm
    assert height >= 2mm

# --- Multi-line variations ---
pass; nested_var=1; another=2

complex_assignment = (
    voltage + resistance
    * capacitance
)

```

## G4 Grammar

```g4
parser grammar AtoParser;

options {
	superClass = AtoParserBase;
	tokenVocab = AtoLexer;
}

file_input: (NEWLINE | stmt)* EOF;

pragma_stmt: PRAGMA;

stmt: simple_stmts | compound_stmt | pragma_stmt;
simple_stmts:
	simple_stmt (SEMI_COLON simple_stmt)* SEMI_COLON? NEWLINE;
simple_stmt:
	import_stmt
	| dep_import_stmt
	| assign_stmt
	| cum_assign_stmt
	| set_assign_stmt
	| connect_stmt
	| directed_connect_stmt
	| retype_stmt
	| pin_declaration
	| signaldef_stmt
	| assert_stmt
	| declaration_stmt
	| string_stmt
	| pass_stmt
	| trait_stmt;

compound_stmt: blockdef | for_stmt;

blockdef: blocktype name blockdef_super? COLON block;
// TODO @v0.4 consider ()
blockdef_super: FROM type_reference;
// TODO @v0.4 consider removing component (or more explicit code-as-data)
blocktype: (COMPONENT | MODULE | INTERFACE);
block: simple_stmts | NEWLINE INDENT stmt+ DEDENT;

// TODO: @v0.4 remove the deprecated import form
dep_import_stmt: IMPORT type_reference FROM string;
import_stmt: (FROM string)? IMPORT type_reference (
		COMMA type_reference
	)*;

declaration_stmt: field_reference type_info;
field_reference_or_declaration:
	field_reference
	| declaration_stmt;
assign_stmt: field_reference_or_declaration '=' assignable;
cum_assign_stmt:
	field_reference_or_declaration cum_operator cum_assignable;
// TODO: consider sets cum operator
set_assign_stmt:
	field_reference_or_declaration (OR_ASSIGN | AND_ASSIGN) cum_assignable;
cum_operator: ADD_ASSIGN | SUB_ASSIGN;
cum_assignable: literal_physical | arithmetic_expression;

assignable:
	string
	| new_stmt
	| literal_physical
	| arithmetic_expression
	| boolean_;

retype_stmt: field_reference ARROW type_reference;

directed_connect_stmt
	: bridgeable ((SPERM | LSPERM) bridgeable)+; // only one type of SPERM per stmt allowed. both here for better error messages
connect_stmt: mif WIRE mif;
bridgeable: connectable;
mif: connectable;
connectable: field_reference | signaldef_stmt | pindef_stmt;

signaldef_stmt: SIGNAL name;
pindef_stmt: pin_stmt;
pin_declaration: pin_stmt;
pin_stmt: PIN (name | number_hint_natural | string);

new_stmt: NEW type_reference ('[' new_count ']')? template?;
new_count: number_hint_natural;

string_stmt:
	string; // the unbound string is a statement used to add doc-strings

pass_stmt:
	PASS; // the unbound string is a statement used to add doc-strings

list_literal_of_field_references:
	'[' (field_reference (COMMA field_reference)* COMMA?)? ']';

iterable_references:
	field_reference slice?
	| list_literal_of_field_references;

for_stmt: FOR name IN iterable_references COLON block;

assert_stmt: ASSERT comparison;

trait_stmt
	: TRAIT type_reference (DOUBLE_COLON constructor)? template?; // TODO: move namespacing to type_reference
constructor: name;
template: '<' (template_arg (COMMA template_arg)* COMMA?)? '>';
template_arg: name ASSIGN literal;

// Comparison operators --------------------
comparison: arithmetic_expression compare_op_pair+;

compare_op_pair:
	lt_arithmetic_or
	| gt_arithmetic_or
	| lt_eq_arithmetic_or
	| gt_eq_arithmetic_or
	| in_arithmetic_or
	| is_arithmetic_or;

lt_arithmetic_or: LESS_THAN arithmetic_expression;
gt_arithmetic_or: GREATER_THAN arithmetic_expression;
lt_eq_arithmetic_or: LT_EQ arithmetic_expression;
gt_eq_arithmetic_or: GT_EQ arithmetic_expression;
in_arithmetic_or: WITHIN arithmetic_expression;
is_arithmetic_or: IS arithmetic_expression;

// Arithmetic operators --------------------

arithmetic_expression:
	arithmetic_expression (OR_OP | AND_OP) sum
	| sum;

sum: sum (PLUS | MINUS) term | term;

term: term (STAR | DIV) power | power;

power: functional (POWER functional)?;

functional: bound | name '(' bound+ ')';

bound: atom;

// Primary elements ----------------

slice:
	'[' (slice_start? COLON slice_stop? (COLON slice_step?)?)? ']'
	// else [::step] wouldn't match
	| '[' ( DOUBLE_COLON slice_step?) ']';
slice_start: number_hint_integer;
slice_stop: number_hint_integer;
slice_step: number_hint_integer;

atom: field_reference | literal_physical | arithmetic_group;

arithmetic_group: '(' arithmetic_expression ')';

literal_physical:
	bound_quantity
	| bilateral_quantity
	| quantity;

bound_quantity: quantity TO quantity;
bilateral_quantity: quantity PLUS_OR_MINUS bilateral_tolerance;
quantity: number name?;
bilateral_tolerance: number_signless (PERCENT | name)?;

key: number_hint_integer;
array_index: '[' key ']';

// backwards compatibility for A.1
pin_reference_end: DOT number_hint_natural;
field_reference_part: name array_index?;
field_reference:
	field_reference_part (DOT field_reference_part)* pin_reference_end?;
type_reference: name (DOT name)*;
// TODO better unit
unit: name;
type_info: COLON unit;
name: NAME;

// Literals
literal: string | boolean_ | number;

string: STRING;
boolean_: TRUE | FALSE;
number_hint_natural: number_signless;
number_hint_integer: number;
number: (PLUS | MINUS)? number_signless;
number_signless: NUMBER;
```

# Most used library modules/interfaces (api of them)

```ato
interface Electrical:
    pass

interface ElectricPower:
    hv = new Electrical
    lv = new Electrical

module Resistor:
    resistance: ohm
    max_power: W
    max_voltage: V
    unnamed = new Electrical[2]

module Capacitor:
    capacitance: F
    max_voltage: V
    unnamed = new Electrical[2]

interface I2C:
    scl = new ElectricLogic
    sda = new ElectricLogic
    frequency: Hz
    address: dimensionless

interface ElectricLogic:
    line = new Electrical
    reference = new ElectricPower
```

For the rest use the atopile MCP server 
- `get_library_interfaces` to list interfaces
- `get_library_modules` to list modules
- `inspect_library_module_or_interface` to inspect the code

# Ato language features

## experimental features

Enable with `#pragma experiment("BRIDGE_CONNECT")`
BRIDGE_CONNECT: enables `p1 ~> resistor ~> p2` syntax
FOR_LOOP: enables `for item in container: pass` syntax
TRAITS: enables `trait trait_name` syntax
MODULE_TEMPLATING: enables `new MyComponent<param=literal>` syntax

## modules, interfaces, parameters, traits

A block is either a module, interface or component.
Components are just modules for code-as-data.
Interfaces describe a connectable interface (e.g Electrical, ElectricPower, I2C, etc).
A module is a block that can be instantiated.
Think of it as the ato equivalent of a class.
Parameters are variables for numbers and they work with constraints.
E.g `resistance: ohm` is a parameter.
Constrain with `assert resistance within 10kohm +/- 10%`.
It's very important to use toleranced values for parameters.
If you constrain a resistor.resistance to 10kohm there won't be a single part found because that's a tolerance of 0%.

Traits mark a module to have some kind of functionality that can be used in other modules.
E.g `trait has_designator_prefix` is the way to mark a module to have a specific designator prefix that will be used in the designator field in the footprint.

## connecting

You can only connect interfaces of the same type.
`resistor0.unnamed[0] ~ resistor0.unnamed[0]` is the way to connect two resistors in series.
If a module has the `can_bridge` trait you can use the sperm operator `~>` to bridge the module.
`led.anode ~> resistor ~> power.hv` connects the anode in series with the resistor and then the resistor in series with the high voltage power supply.

## for loop syntax

`for item in container: pass` is the way to iterate over a container.

# Ato CLI

## How to run

You run ato commands through the MCP tool.

## Packages

Packages can be found on the ato registry.
To install a package you need to run `ato add <PACKAGE_NAME>`.
e.g `ato install atopile/addressable-leds`
And then can be imported with `from "atopile/addressable-leds/sk6805-ec20.ato" import SK6805_EC20_driver`.
And used like this:

```ato
module MyModule:
    led = new SK6805_EC20_driver
```

## Footprints & Part picking

Footprint selection is done through the part choice (`ato create part` auto-generates ato code for the part).
The `pin` keyword is used to build footprint pinmaps so avoid using it outside of `component` blocks.
Preferrably use `Electrical` interface for electrical interfaces.
A lot of times it's actually `ElectricLogic` for things like GPIOs etc or `ElectricPower` for power supplies.

Passive modules (Resistors, Capacitors) are picked automatically by the constraints on their parameters.
To constrain the package do e.g `package = "0402"`.
To explictly pick a part for a module use `lcsc = "<LCSC_PART_NUMBER>"`.

# Creating a package

Package generation process:

Review structure of other pacakges.

1. Create new Directory in 'packages/packages' with naming convention '<vendor>-<device>' eg 'adi-adau145x'
2. create an ato.yaml file in the new directory with the following content:

```yaml
requires-atopile: '^0.9.0'

paths:
    src: '.'
    layout: ./layouts

builds:
    default:
        entry: <device>.ato:<device>_driver
    example:
        entry: <device>.ato:Example
```

3. Create part using tool call 'search_and_install_jlcpcb_part'
4. Import the part into the <device>.ato file
5. Read the datasheet for the device
6. Find common interfaces in the part eg I2C, I2S, SPI, Power

7. Create interfaces and connect them

power interfaces:
power*<name> = new ElectricPower
power*<name>.required = True # If critical to the device
assert power\*<name>.voltage within <minimum*operating_voltage>V to <maximum_operating_voltage>V
power*<name>.vcc ~ <device>.<vcc pin>
power\_<name>.gnd ~ <device>.<gnd pin>

i2c interfaces:
i2c = new I2C
i2c.scl.line ~ <device>.<i2c scl pin>
i2c.sda.line ~ <device>.<i2c sda pin>

spi interfaces:
spi = new SPI
spi.sclk.line ~ <device>.<spi sclk pin>
spi.mosi.line ~ <device>.<spi mosi pin>
spi.miso.line ~ <device>.<spi miso pin>

8. Add decoupling capacitors

looking at the datasheet, determine the required decoupling capacitors

eg: 2x 100nF 0402:

power_3v3 = new ElectricPower

# Decoupling power_3v3

power_3v3_caps = new Capacitor[2]
for capacitor in power_3v3_caps:
capacitor.capacitance = 100nF +/- 20%
capacitor.package = "0402"
power_3v3.hv ~> capacitor ~> power_3v3.lv

9. If device has pin configurable i2c addresses

If format is: <n x fixed address bits><m x pin configured address bits>
use addressor module:

- Use `Addressor<address_bits=N>` where **N = number of address pins**.
- Connect each `address_lines[i].line` to the corresponding pin, and its `.reference` to a local power rail.
- Set `addressor.base` to the lowest possible address and `assert addressor.address is i2c.address`.

10. Create a README.md

# <Manufacturer> <Manufacturer part number> <Short description>

## Usage

```ato
<copy in example>

```

## Contributing

Contributions to this package are welcome via pull requests on the GitHub repository.

## License

This atopile package is provided under the [MIT License](https://opensource.org/license/mit/).

11. Connect high level interfaces directly in example:

eg:

i2c = new I2C
power = new ElectricPower
sensor = new Sensor

i2c ~ sensor.i2c
power ~ sensor.power_3v3

# Additional Notes & Gotchas (generic)

- Multi-rail devices (VDD / VDDIO, AVDD / DVDD, etc.)

    - Model separate `ElectricPower` interfaces for each rail (e.g. `power_core`, `power_io`).
    - Mark each `.required = True` if the device cannot function without it, and add voltage assertions per datasheet.

- Optional interfaces (SPI vs I²C)

    - If the device supports multiple buses, pick one for the initial driver. Leave unused bus pins as `ElectricLogic` lines or expose a second interface module later.

- Decoupling guidance

    - If the datasheet shows multiple caps, model the **minimum required** set so the build passes; you can refine values/packages later.

- File / directory layout recap
    - `<vendor>-<device>/` – package root
    - `ato.yaml` – build manifest (include `default` **and** `example` targets)
    - `<device>.ato` – driver + optional example module
    - `parts/<MANUFACTURER_PARTNO>/` – atomic part + footprint/symbol/step files

These tips should prevent common "footprint not found", "pin X missing", and build-time path errors when you add new devices.

# Vibe coding a project

If the user gives you high level description of the project, use the following guide:

# How LLMs can design electronics:

#1 Rule: USE THE TOOLS. If the tools dont work, dont freak out, you are probably using them wrong. Ask for help if you get stuck.

Top level design

1. Research available packages relevant to the user requests using 'find_packages'
2. Inspect promising packages using 'inspect_package'
3. Propose packages to use for project and architucture to user, revise if needed
4. Install needed packages using 'install_package'
5. Import packages into main file
6. Create instances of packages in main module

## Power

1. Review for each package the required voltage and current (current may not be provided, use judement if nessesary)
2. Determine the power rails that need to be generated and a suitable tollerance (typically ~3-5% is acceptable)
3. Determine the input power source, typically a battery, USB connector or other power connector (eg XT30) and install relevant package
4. Find suitable regulators:
   a) if input voltage > required voltage and current is low, use an LDO package
   b) if input voltage > required voltage and current is high, use buck converter
   c) if input votlage < required voltage, use a boost converter
   d) if input voltage can be both less than or greater than input voltage, use buck boost (eg battery powered device that needs 3v3)
5. If battery powered, add charger package

Typical power architucture example with LDO:

- USB input power
- Low current output (eg microcontroller)

from "atopile/ti-tlv75901/ti-tlv75901.ato" import TLV75901_driver
from "atopile/usb-connectors/usb-connectors.ato" import USBCConn

module App:

    # Rails
    power_5v = new Power
    power_3v3 = new Power

    # Components
    ldo = new TLV75901_driver
    usb_connector = new USBCConn

    # Connections
    usb_connector.power ~ power_vbus
    power_vbus ~> ldo ~> power_3v3

## Communicaions

1. Review packages required interfaces, typically i2c, spi or ElectricLogics
2. Find suitable pins on the controller, typically a microcontroller or Linux SOC
3. Connect interfaces eg micro.i2c[0] ~ sensor.i2c

## Development process notes

- After making changes, be sure to use 'build_project' to update the PCB
- Builds will often generate errors/warnings, these should be reviewed and fixed
- Prioritize pacakges from 'atopile' over other packages

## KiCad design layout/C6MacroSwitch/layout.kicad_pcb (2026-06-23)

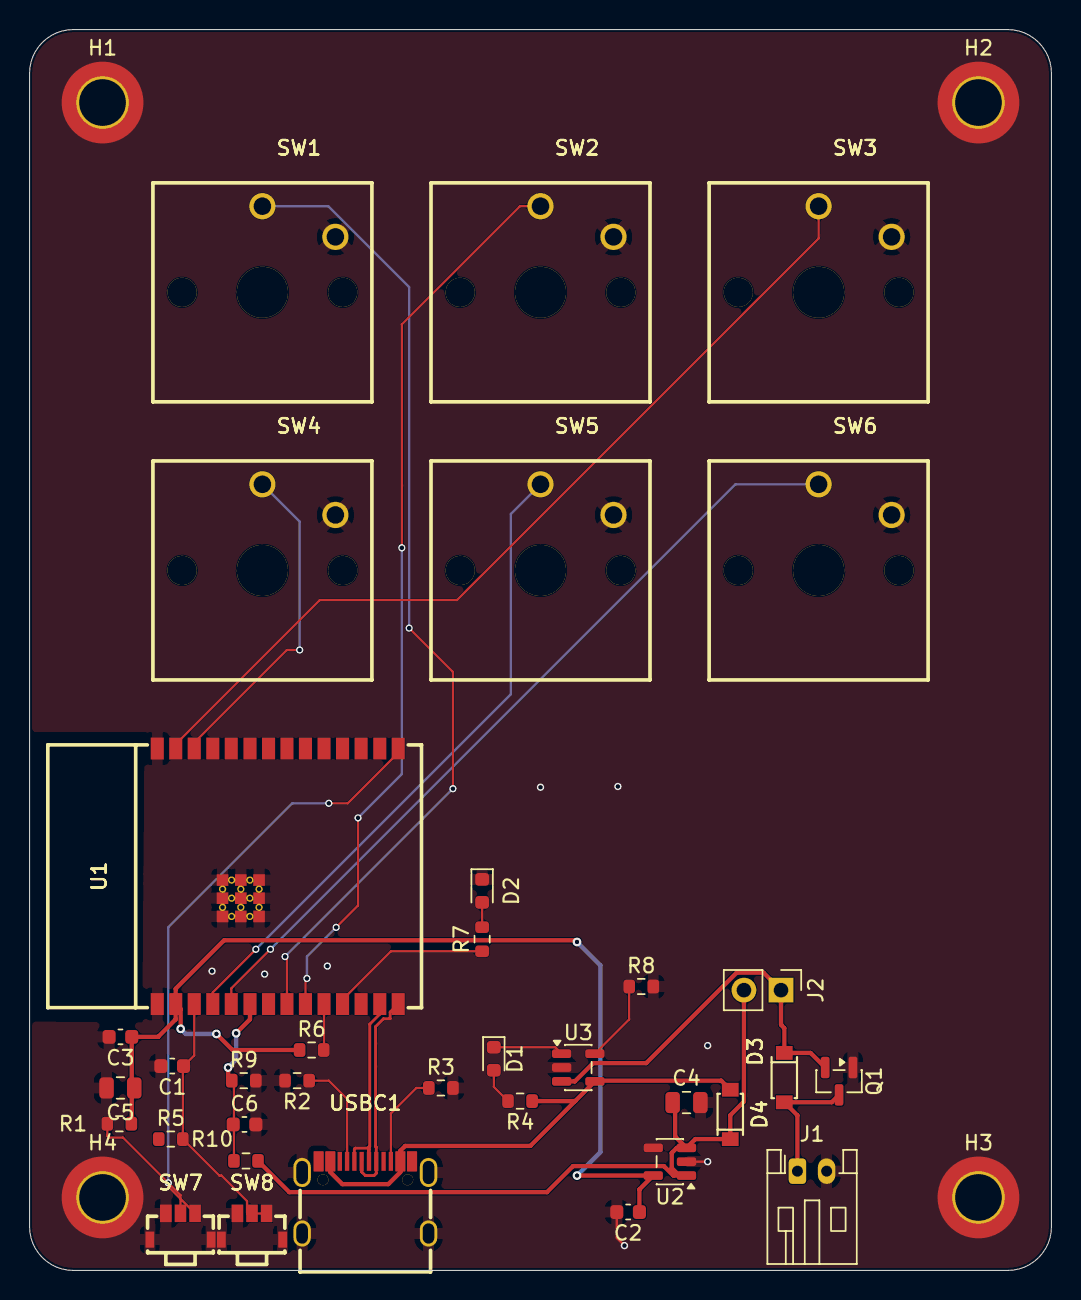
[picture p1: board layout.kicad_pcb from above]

Board: 2 copper layers, 70.0 x 85.0 mm, 39 parts (0 on the bottom side), 25 nets.

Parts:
C1: GCM188R71E105KA64D; C_0603_1608Metric
C2: GRM188Z71A106KA73D; C_0603_1608Metric
C3, C6: GRM188R72A104KA35D; C_0603_1608Metric
C4, C5: GRM21BZ71E106KE15K; C_0805_2012Metric
D1: LED RED; LED_0603_1608Metric
D2: LED GREEN; LED_0603_1608Metric
D3, D4: 1N5817W; SOD-123_L2.7-W1.6-LS3.6-RD
H1, H2, H3, H4: M3 DIN965 TopBottom; MountingHole_3.2mm_M3_DIN965_Pad_TopBottom
J1: S2B-PH-K-S(LF)(SN); JST_PH_S2B-PH-K_1x02_P2.00mm_Horizontal
J2: 61300211121; PinHeader_1x02_P2.54mm_Vertical
Q1: AO3401A; SOT-23
R1, R5, R6: ERJ-3EKF1002V; R_0603_1608Metric
R2, R3: ERJ-3EKF5101V; R_0603_1608Metric
R4, R7: ERJ-3EKF1001V; R_0603_1608Metric
R8: ERJ-3EKF2001V; R_0603_1608Metric
R9, R10: ERJ-3EKF1004V; R_0603_1608Metric
SW1, SW2, SW3, SW4, SW5, SW6: CPG135001D01; KEY-TH_CPG135001D0X
SW7, SW8: TSA061B2808B; SW-SMD_TSA061B2808B
U1: ESP32-C6-WROOM-1-N8; WIRELM-SMD_ESP32-C6-WROOM-1
U2: XC6220B331MR-G; SOT-23-5
U3: MCP73831T-2ACI/OT; SOT-23-5
USBC1: TYPE-C-31-M-12; USB-C_SMD-TYPE-C-31-M-12_1

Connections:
3V3: C2.1, C3.1, C5.1, R1.1, R5.1, R6.1, U1.2, U2.5
BAT_RAW: D3.2, J1.1, Q1.3
BOOT: R1.2, SW7.1, SW7.2, U1.15
CC1: R2.1, USBC1.A5
CC2: R3.1, USBC1.B5
CHG_LED_A: D1.2, R4.2
CHG_PROG: R8.1, U3.5
CHG_STAT: D1.1, U3.1
EN: C1.1, R5.2, SW8.1, SW8.2, U1.3
GND: C1.2, C2.2, C3.2, C4.2, C5.2, C6.2, D2.1, H1.1, H2.1, H3.1, H4.1, J1.2, Q1.1, R2.2, R3.2, R8.2, R9.2, SW1.2, SW2.2, SW3.2, SW4.2, SW5.2, SW6.2, SW7.3, SW7.4, SW7.5, SW8.3, SW8.4, SW8.5, U1.1, U1.28, U1.29, U1.30, U1.31, U1.32, U1.33, U1.34, U1.35, U1.36, U1.37, U2.2, U3.2, USBC1.1, USBC1.2, USBC1.3, USBC1.4, USBC1.A1B12, USBC1.B1A12
IO8_STRAP: R6.2, U1.10
KEY1: SW1.1, U1.8
KEY2: SW2.1, U1.9
KEY3: SW3.1, U1.27
KEY4: SW4.1, U1.26
KEY5: SW5.1, U1.4
KEY6: SW6.1, U1.5
LED: R7.1, U1.11
LED_A: D2.2, R7.2
USB_D_N: U1.13, USBC1.A7, USBC1.B7
USB_D_P: U1.14, USBC1.A6, USBC1.B6
VBAT: D3.1, J2.1, Q1.2, U3.3
VBAT_SENSE: C6.1, R9.1, R10.2, U1.6
VBAT_SW: C4.1, D4.1, J2.2, R10.1, U2.1, U2.3
VBUS: D4.2, R4.1, U3.4, USBC1.A4B9, USBC1.B4A9

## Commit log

2026-02-17 wip: ESP32-C6 dev board schematic and parts
    Full schematic: USB-C x2, AMS1117-3.3 LDO, CH340G debug UART,
    12MHz crystal, GPIO header, buttons, LED, mounting holes.
    Auto-picked passives (0603/0805). Mounting holes WIP (needs ato 0.14+).
    [C0603_L1.6-W0.8-H0.8.step, C0805_L2.0-W1.3-H1.3.step, CONN-TH_XD-XHD-2-4A.STEP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]
2026-02-17 Upgrade to atopile 0.14 and use official mounting-holes package
    - Bump requires-atopile to ^0.14.0, mounting-holes dep to 0.2.0
    - Switch from local MountingHole_M3 workaround to official package
    - Remove local parts/MountingHole_3_2_M3_Pad (now from package)
    - Add S8050 NPN transistor part for upcoming auto-reset circuit
    - Parts updated by atopile 0.14 build (traits, symbols, footprints)
    [SOT-23-3L_L2.9-W1.6-H1.1-LS2.8-P0.95.step, default.kicad_pcb]
2026-02-17 Add MountingHole part library to fp-lib-table
2026-02-17 Add Changjiang S8050 transistors and auto-reset circuit to schematic
2026-02-17 board layout
    [default.kicad_pcb]
2026-02-18 Replace ESP32-C6-MINI-1 footprint and 3D models
    [WIFIM-SMD_61P-L16.6-W13.2-P0.80-ESP32-C6-MINI-1-N4.step]
2026-02-18 Update PCB and passive footprints from ato build
    [default.kicad_pcb]
2026-02-18 Replace 7 GPIO pullup resistors with two C29718 resistor arrays
    [R0603-8P_L3.2-W1.6-H0.6.step, default.kicad_pcb]
2026-02-19 Name USB signals with _P/_N suffixes for KiCad differential pair routing
    Rename USB-C connector D+/D- signals (DP1/DN1 → D_P/D_N) and CH340G
    signals (UDpos/UDneg → UD_P/UD_N) so KiCad auto-detects both USB
    differential pairs (esp32-D_P/N and ch340g-D_P/N).
    Also reorder RN1/RN2 pullup array GPIO assignments so pin order
    descends left-to-right matching the header physical layout.
    [default.kicad_pcb]
2026-02-19 Layout quasi ok.
    [default.kicad_pcb]
2026-02-26 New footprint for C6
    [default.kicad_pcb]
2026-04-19 Mssing parts
    [C0402_L1.0-W0.5-H0.5.step, HDR-TH_4P-P2.54-V-F.step, KEY-TH_CPG135001D0X.step]
2026-04-19 Modded kicad files
    [default.kicad_pcb]
2026-06-11 chore: install diodeinc/pcb agent skills
2026-06-11 docs: add design spec for C6 Zigbee macro switch (Zener variant)
2026-06-11 docs: macro keys are Kailh Choc CPG135001D01 mechanical switches
2026-06-11 docs: implementation plan for C6 Zigbee macro switch (Zener)
2026-06-11 feat(zener): scaffold pcb workspace for C6MacroSwitch
2026-06-11 feat(zener): ESP32-C6-WROOM-1-N8 component (reused verified sym/fp)
2026-06-11 feat(zener): TYPE-C-31-M-12 USB-C connector component
2026-06-11 feat(zener): Kailh Choc CPG135001D01 switch component
2026-06-11 feat(zener): tactile button and 1N5817W Schottky components
2026-06-11 feat(zener): XC6220 LDO, MCP73831 charger and JST-PH battery connector
2026-06-11 feat(zener): complete C6MacroSwitch top-level wiring
    [layout.kicad_pcb]
2026-06-11 feat(zener): KiCad 10 round-trip verified (pcbnew resave + layout resync)
    [layout.kicad_pcb]
2026-06-11 docs(zener): board README with GPIO map and power architecture
2026-06-12 refactor(zener): promuovi il progetto Zener a root del repo
    Rimosso il vecchio progetto atopile (main.ato, keypad.ato, ato.yaml,
    parts/, layouts/, tmp/) e spostato il workspace Zener da zener/ alla
    root: C6MacroSwitch.zen, components/, layout/, pcb.toml diventano
    top-level. Adottati README e .gitignore (KiCad) di Zener.
    atopile resta recuperabile da git history; la migrazione è motivata
    da atopile <=0.15.7 che non rilegge i PCB salvati da KiCad 10.
    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
    [C0402_L1.0-W0.5-H0.5.step, C0603_L1.6-W0.8-H0.8.step, C0805_L2.0-W1.3-H1.3.step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]
2026-06-12 fix(zener): porta i LED a 0603 e fissa il vincolo package
    I due LED (D_CHG, D_LED) erano gli unici footprint 0402, fuori dalla
    specifica hardware. Portati a 0603 come R e C. CLAUDE.md aggiornato:
    resistenze, condensatori e LED in 0603 o più grande, mai 0402.
2026-06-12 docs(zener): LED 0603 in casa, nessun MPN richiesto
    I LED sono generici 0603 già disponibili: come il modulo ESP32 non
    serve un part number. Documentato in CLAUDE.md e con un commento sul
    design che il warning di build "No house LED found ... 0603" è atteso.
2026-06-12 feat(zener): resync layout KiCad ai LED 0603
    Rigenerato il .kicad_pcb dopo il cambio package dei LED: i footprint
    D_CHG/D_LED passano da LED_0402_1005Metric a LED_0603_1608Metric,
    piazzamento preservato. Allinea il layout al design.
    [layout.kicad_pcb]
2026-06-12 feat(zener): piazza i 6 Choc su griglia 1u 2x3 (pitch 19.05mm)
    Switch macro disposti su griglia 2x3 a pitch MX 1u (19.05mm) con stessa
    rotazione; origine footprint compensata per l'offset del polo centrale
    (-2.5,+4.85) così i centri keycap cadono su coordinate pulite. Nessuna
    collisione Choc-Choc.
    WIP floorplan: il cluster si sovrappone al supporto (ESP32/passivi),
    da riposizionare sotto i tasti nella fase di layout finale.
    [layout.kicad_pcb]
2026-06-12 feat(zener): primo sbroglio e layout della board
    Prima passata di routing manuale in KiCad: 151 tracce, 17 via e 3 zone
    di rame, con relative net class e impostazioni di progetto.
    [layout.kicad_pcb]
2026-06-12 fix(zener): review fixes — LDO caps 10uF, reverse-battery Q/D options, IO8 strap pullup, LED to IO10, Choc NPTH+courtyard
    [layout.kicad_pcb]
2026-06-12 fix(zener): LDO caps to 0805 for DC-bias derating margin
    [layout.kicad_pcb]
2026-06-13 feat(zener): 4x M3 corner mounting holes (GND) + 3mm rounded board corners
    [layout.kicad_pcb]
2026-06-13 feat(zener): ulteriore sbroglio e layout della board
    [layout.kicad_pcb]
2026-06-13 fix(zener): thermal vias on ESP32-C6 EP pads (fixes isolated GND pad 33, improves RF ground)
